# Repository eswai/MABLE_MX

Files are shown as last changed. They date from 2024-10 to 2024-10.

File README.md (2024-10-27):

# MABLE

MABLEはワイヤレス、左右分割、36キーのコンパクトなキーボードです。
キーボードカレンダー2024年3月に掲載されました。

* MiniAxe互換キーレイアウト
* 省電力なnRF52840採用
* Bluetooth接続、電池内蔵の完全ワイヤレス
* USB-Cからバッテリー充電 (リチウムポリマー電池の取り扱いにはご注意ください)
* ZMK firmwareもしくはKMK firmware
* 3Dプリンタ製のケース

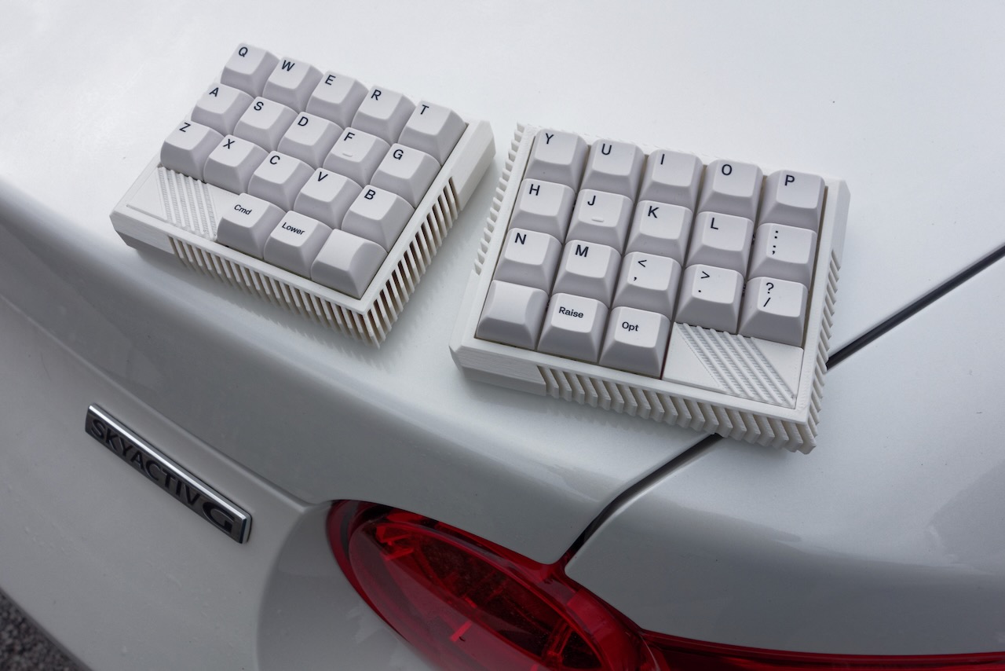
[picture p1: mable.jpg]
MABLE


## BOM

遊舎工房、TALP KEYBOARD、スイッチサイエンス(SS)、千石電商などで入手可能です。(2024/10時点で欠品の部品がいくつかありました)

| TH | TH | 数量 | 入手先 |
| ---- | ---- | ---- | ---- |
| PCB | オリジナル | 左右各1 | |
| マイコン | Seeed Studio XIAO nRF52840 | 2 | |
| バッテリー | リチウムイオンポリマー電池110mAh DPTL-DTP401525 | 2 | SS |
| バッテリーコネクタ | JST製2ピンPHコネクタ用ソケット JST-S2B-PH-K-S  | 2 | SS |
| キーキャップ| MXスイッチ用1Uサイズ|36| |
| キースイッチ | Cherry MX互換スイッチ | 36 | |
| スイッチソケット | MXスイッチ用 Kailh PCBソケット | 36 | |
| ダイオード | 1N4148 ダイオード (SMD) | 36 | |
| スライドスイッチ | 小型スライドスイッチ 1回路2接点(面実装タイプ)  SSW1P2T-SMT | 2 | 千石 |
| ケース | 3Dプリンタ製 | 1セット (6部品) | |
| ねじ | M2 L=6 | 10  | |
| ゴム足 | 3M クッションゴム 9.5x3.8mm 丸形 CS-02 透明 | 8  | |

## 組み立て

TBD

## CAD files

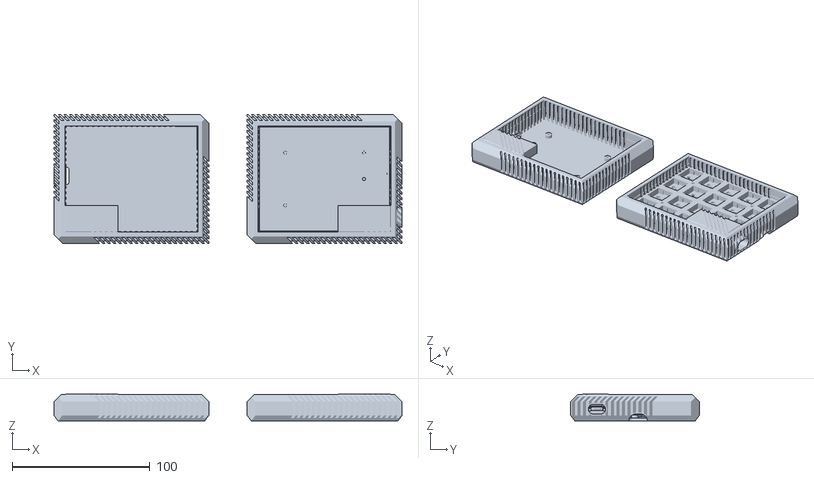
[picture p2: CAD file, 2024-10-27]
case/mable_case_5 v52.stl
252.2 x 93.2 x 19.5

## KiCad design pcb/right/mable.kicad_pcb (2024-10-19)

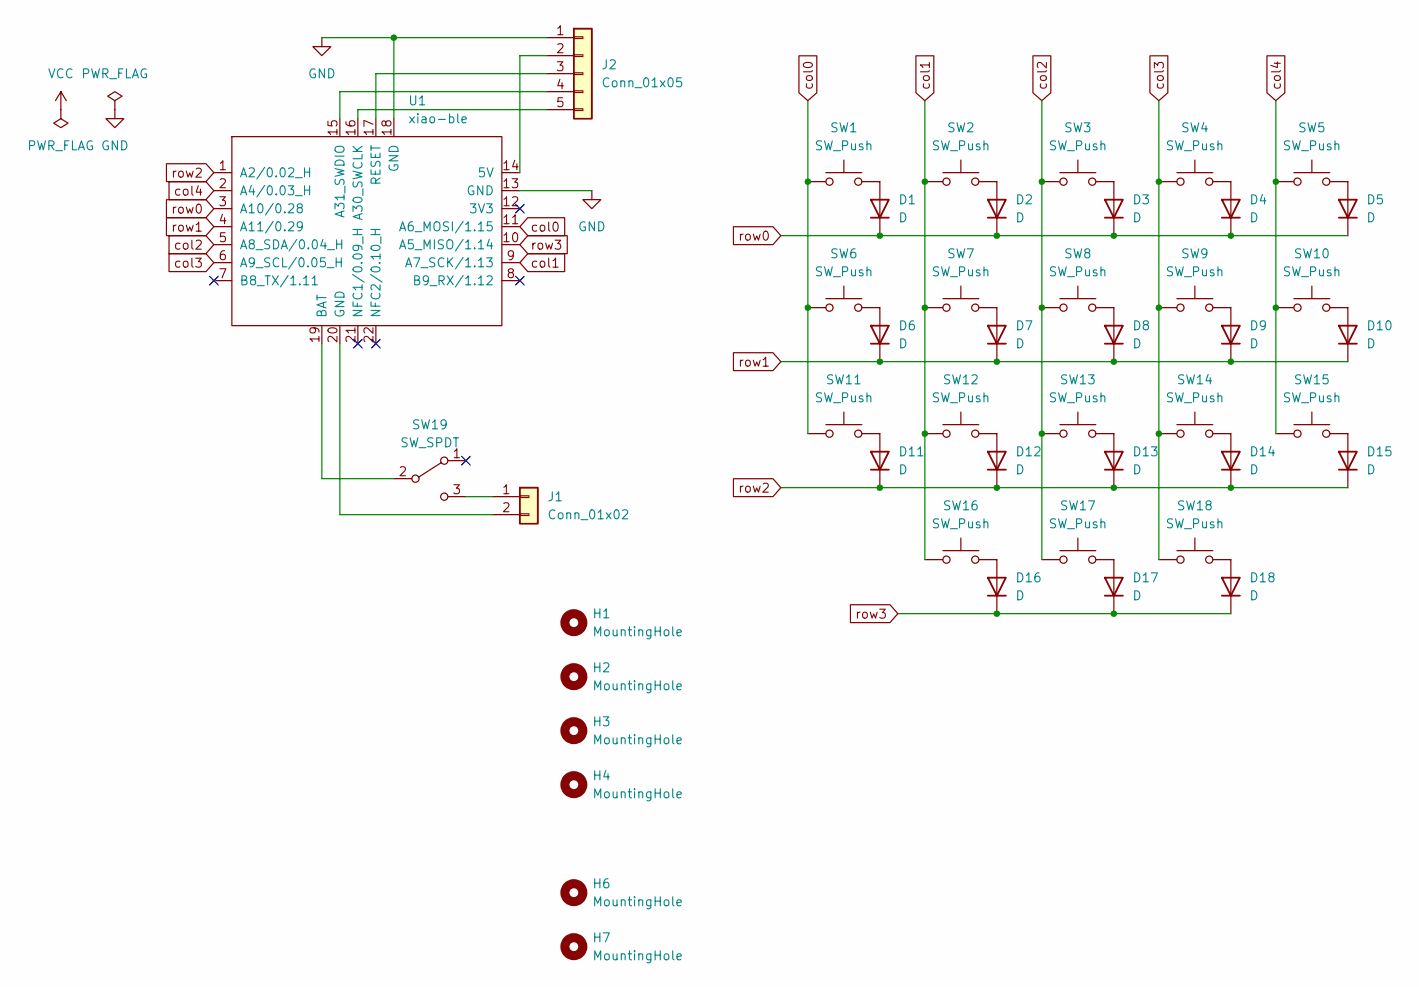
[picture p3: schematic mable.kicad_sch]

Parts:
D1, D2, D3, D4, D5, D6, D7, D8, D9, D10, D11, D12, D13, D14, D15, D16, D17, D18: D; D_SOD-123F
H1, H2, H3, H4, H6, H7: MountingHole; MountingHole_2.2mm_M2
J1: Conn_01x02; JST_PH_B2B-PH-K_1x02_P2.00mm_Vertical
J2: Conn_01x05; PinHeader_1x05_P2.54mm_Vertical
SW1, SW2, SW3, SW4, SW5, SW6, SW7, SW8, SW9, SW10, SW11, SW12, SW13, SW14, SW15, SW16, SW17, SW18: SW_Push; MX-Hotswap-1U
SW19: SW_SPDT; SSW1P2T-SMT
U1: xiao-ble; xiao-ble-tht

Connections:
GND: J2.1, U1.13 (GND), U1.18 (GND)
unnamed: D1.2 (A), SW1.2
unnamed: D2.2 (A), SW2.2
unnamed: D3.2 (A), SW3.2
unnamed: D4.2 (A), SW4.2
unnamed: D5.2 (A), SW5.2
unnamed: D6.2 (A), SW6.2
unnamed: D7.2 (A), SW7.2
unnamed: D8.2 (A), SW8.2
unnamed: D9.2 (A), SW9.2
unnamed: D10.2 (A), SW10.2
unnamed: D11.2 (A), SW11.2
unnamed: D12.2 (A), SW12.2
unnamed: D13.2 (A), SW13.2
unnamed: D14.2 (A), SW14.2
unnamed: D15.2 (A), SW15.2
unnamed: D16.2 (A), SW16.2
unnamed: D17.2 (A), SW17.2
unnamed: D18.2 (A), SW18.2
unnamed: J1.1, SW19.3 (C)
unnamed: J1.2, U1.20 (GND)
unnamed: J2.2, U1.14 (5V)
unnamed: J2.3, U1.17 (RESET)
unnamed: J2.4, U1.15 (A31_SWDIO)
unnamed: J2.5, U1.16 (A30_SWCLK)
unnamed: SW19.2 (B), U1.19 (BAT)
col0: SW1.1, SW6.1, SW11.1, U1.11 (A6_MOSI/1.15)
col1: SW2.1, SW7.1, SW12.1, SW16.1, U1.9 (A7_SCK/1.13)
col2: SW3.1, SW8.1, SW13.1, SW17.1, U1.5 (A8_SDA/0.04_H)
col3: SW4.1, SW9.1, SW14.1, SW18.1, U1.6 (A9_SCL/0.05_H)
col4: SW5.1, SW10.1, SW15.1, U1.2 (A4/0.03_H)
row0: D1.1 (K), D2.1 (K), D3.1 (K), D4.1 (K), D5.1 (K), U1.3 (A10/0.28)
row1: D6.1 (K), D7.1 (K), D8.1 (K), D9.1 (K), D10.1 (K), U1.4 (A11/0.29)
row2: D11.1 (K), D12.1 (K), D13.1 (K), D14.1 (K), D15.1 (K), U1.1 (A2/0.02_H)
row3: D16.1 (K), D17.1 (K), D18.1 (K), U1.10 (A5_MISO/1.14)

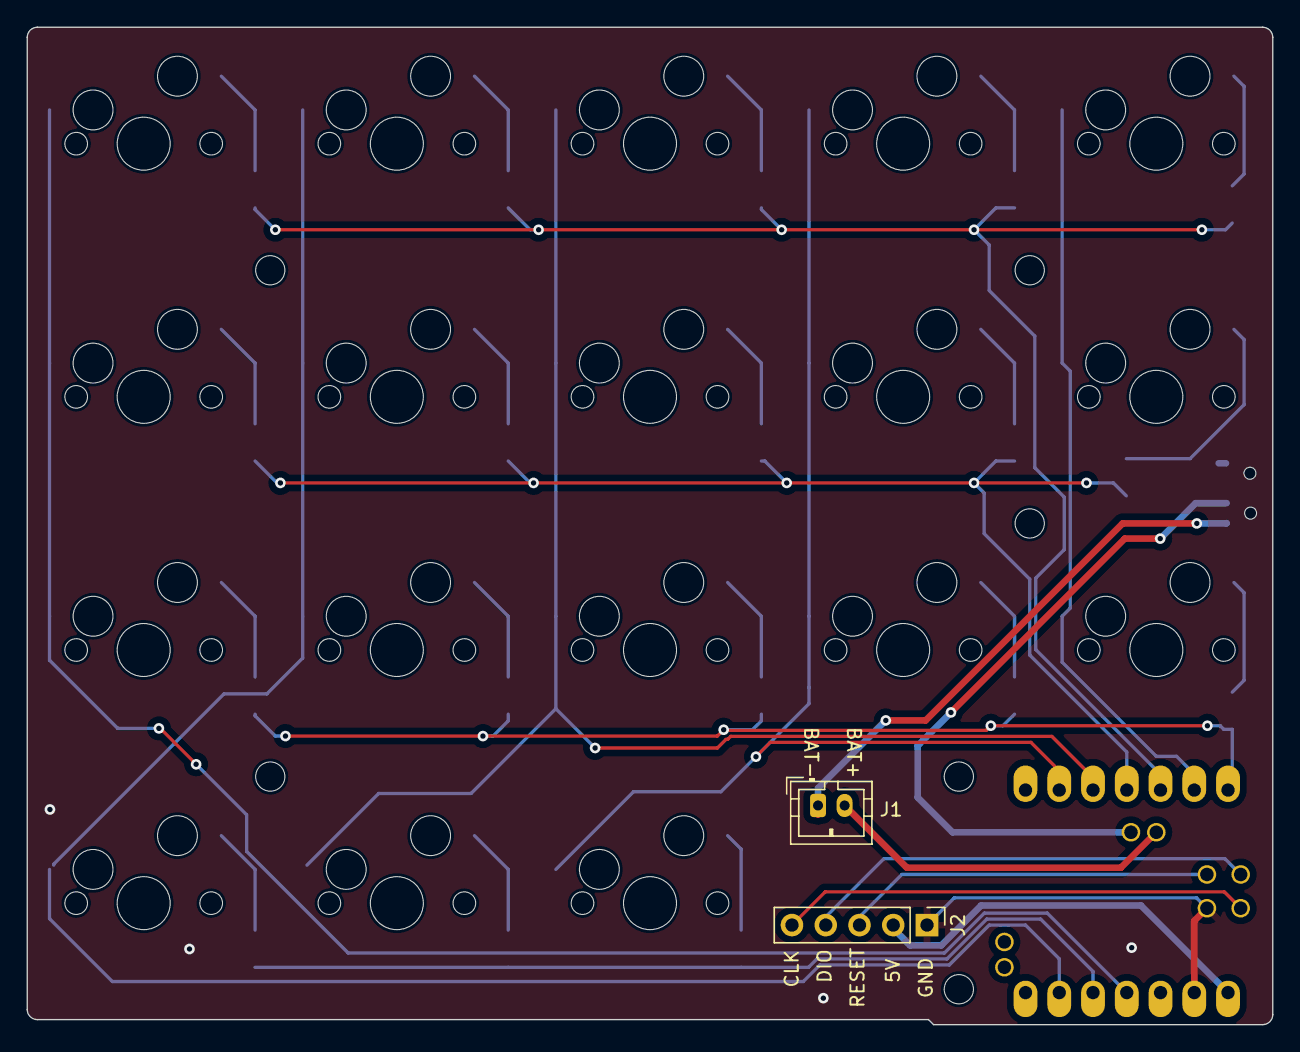
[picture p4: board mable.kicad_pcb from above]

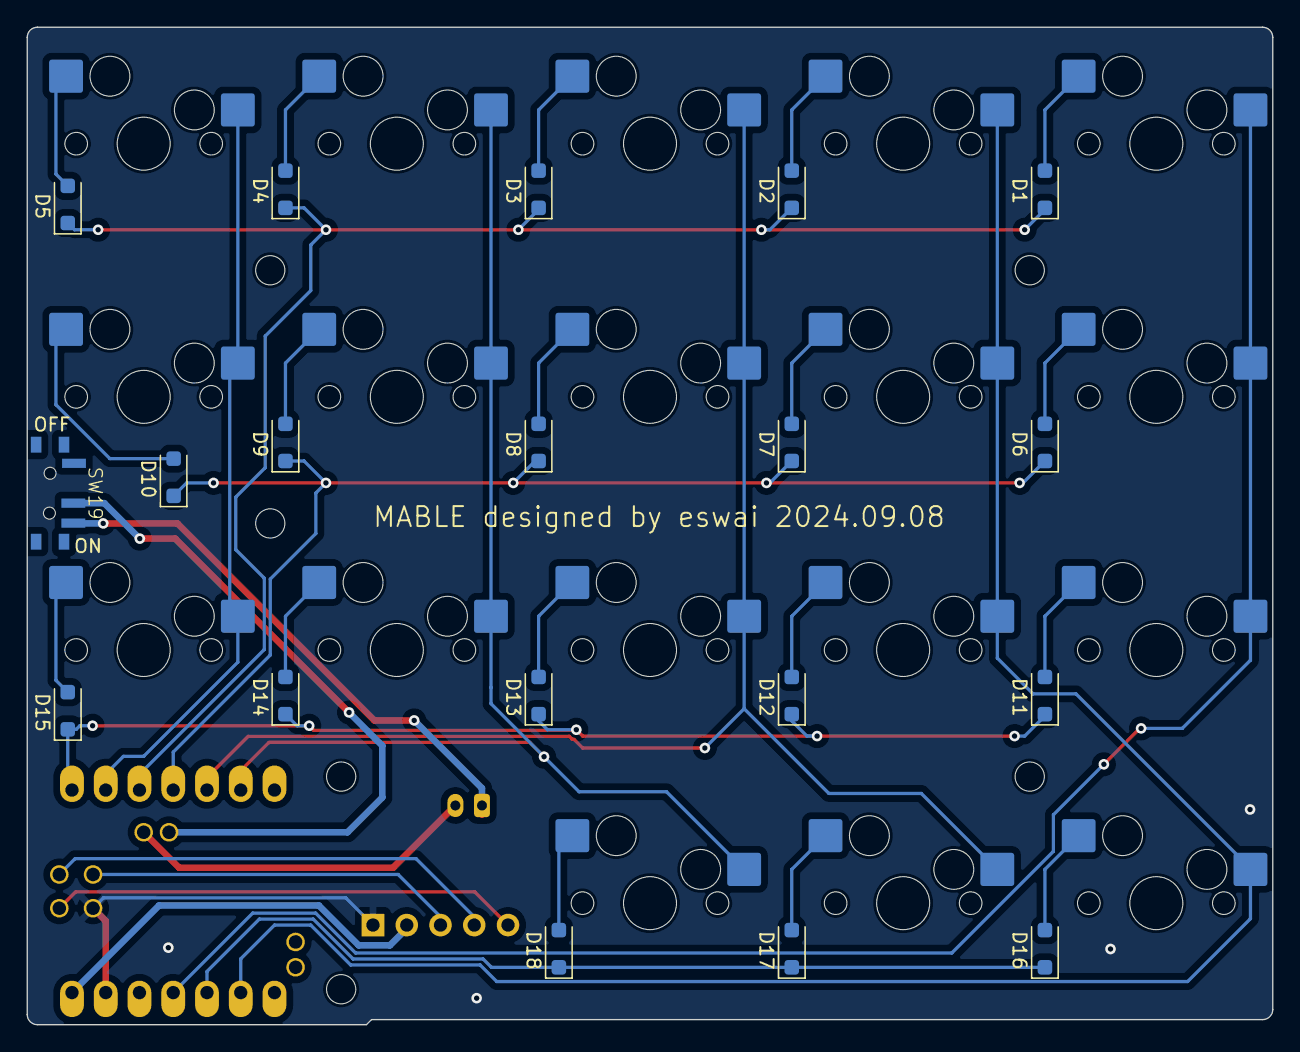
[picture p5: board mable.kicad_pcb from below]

Board: 2 copper layers, 93.7 x 75.1 mm, 46 parts (19 on the bottom side), 35 nets.
